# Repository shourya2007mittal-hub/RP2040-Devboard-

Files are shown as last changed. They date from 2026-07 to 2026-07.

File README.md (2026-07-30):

# RP2040-Devboard-



SO I made a custom Rp2040 Dev-board for myself . I tried to make a dev board in which I have the access to almost all the gpio/analog pins available on the Rp2040 . It also holds an USB-C Type interference for communication and 3.3V Voltage regulator and Crystal oscillator , Flash Memory , boot pin and LEDS and battery connector and more.

## Features

- Based on RP-2040 Chip
- Has MCP1700x-330xxTT as Voltage Regualtor 
- Has W25Q16JVUXIQTR as Flash Memory
- Uses 2 set of 18 connector pins
- Has on-Board LEDS and battery connector 

## Cost Summary (BOM)

| Item | Quantity | Price (USD) | Source |
|---|---|---|---|
| PCB + PCBA + Shipping  | 1 | $83.94 | JLCPCB |

**Total Estimated Cost:** **$83.94**

### Schematic


### PCB Design



### 3D Design



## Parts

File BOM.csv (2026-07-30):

Item | Quantity | Price | Source
PCB + PCBA + Shipping | 1 | 83.94 | JLCPCB

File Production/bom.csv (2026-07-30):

Designator | Footprint | Quantity | Value | LCSC Part #
C1 | 0402 | 1 | 1uF
C13, C14 | 0603 | 2 | 10uF
C15, C16 | 0402 | 2 | 33pF
C17, C2, C3, C4, C5, C6, C7, C8, C9 | 0402 | 9 | 0.1uF
D1, D4, D5 | 0201 | 3 | LED
J1 | USB_C_Receptacle_G-Switch_GT-USB-7010ASV | 1 | USB_C_Receptacle_USB2.0_16P
J2, J3 | PinHeader_1x20_P2.54mm_Vertical | 2 | Conn_01x20
J4 | PinHeader_1x03_P2.54mm_Vertical | 1 | Conn_01x03
J6 | Hirose_DF13-02P-1.25DSA_1x02_P1.25mm_Vertical | 1 | Conn_01x02_Pin
R1, R2 | 0603 | 2 | 33 R
R10, R12, R13 | 0603 | 3 | 1K
R3, R4 | 0603 | 2 | 50K
R5, R6 | 0402 | 2 | 1K
R7 | 0402 | 1 | 10K
R8, R9 | 0402 | 2 | 27
SW1 | SW_Push_SPST_NO_Alps_SKRK | 1 | SW_Push
U1 | QFN-56-1EP_7x7mm_P0.4mm_EP3.2x3.2mm | 1 | RP2040
U2 | SOT-23 | 1 | MCP1700x-330xxTT
U4 | Winbond_USON-8-1EP_3x2mm_P0.5mm_EP0.2x1.6mm | 1 | W25Q16JVUXIQ TR
Y1 | Crystal_SMD_3225-4Pin_3.2x2.5mm | 1 | 12 MHz

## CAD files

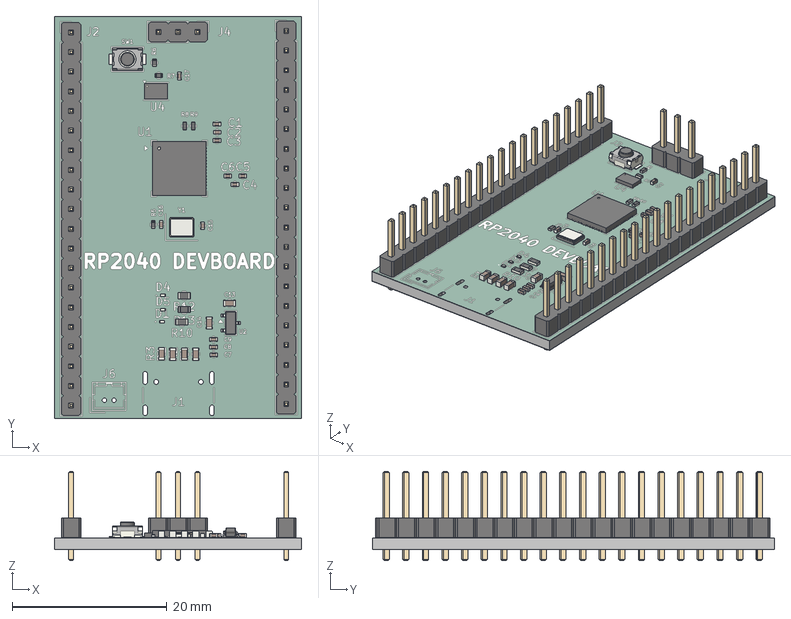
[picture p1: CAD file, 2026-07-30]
CAD/RP2040 Devboard.step
32.0 x 52.0 x 11.5 mm
C_0402_1005Metric x 12
R_0402_1005Metric x 5
Winbond_USON-8-1EP_3x2mm_P0.5mm_EP0.2x1.6mm
LED_0201_0603Metric x 3
C_0603_1608Metric x 6
R_0603_1608Metric x 3
QFN-56-1EP_7x7mm_P0.4mm_EP3.2x3.2mm
PinHeader_1x20_P2.54mm_Vertical x 2
SW_Push_SPST_NO_Alps_SKRK
Crystal_SMD_3225-4Pin_3.2x2.5mm
SOT-23
PinHeader_1x03_P2.54mm_Vertical
RP2040 Devboard_silkscreen
RP2040 Devboard_soldermask x 2
RP2040 Devboard_PCB

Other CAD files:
CAD/RP2040 Devboard.f3d

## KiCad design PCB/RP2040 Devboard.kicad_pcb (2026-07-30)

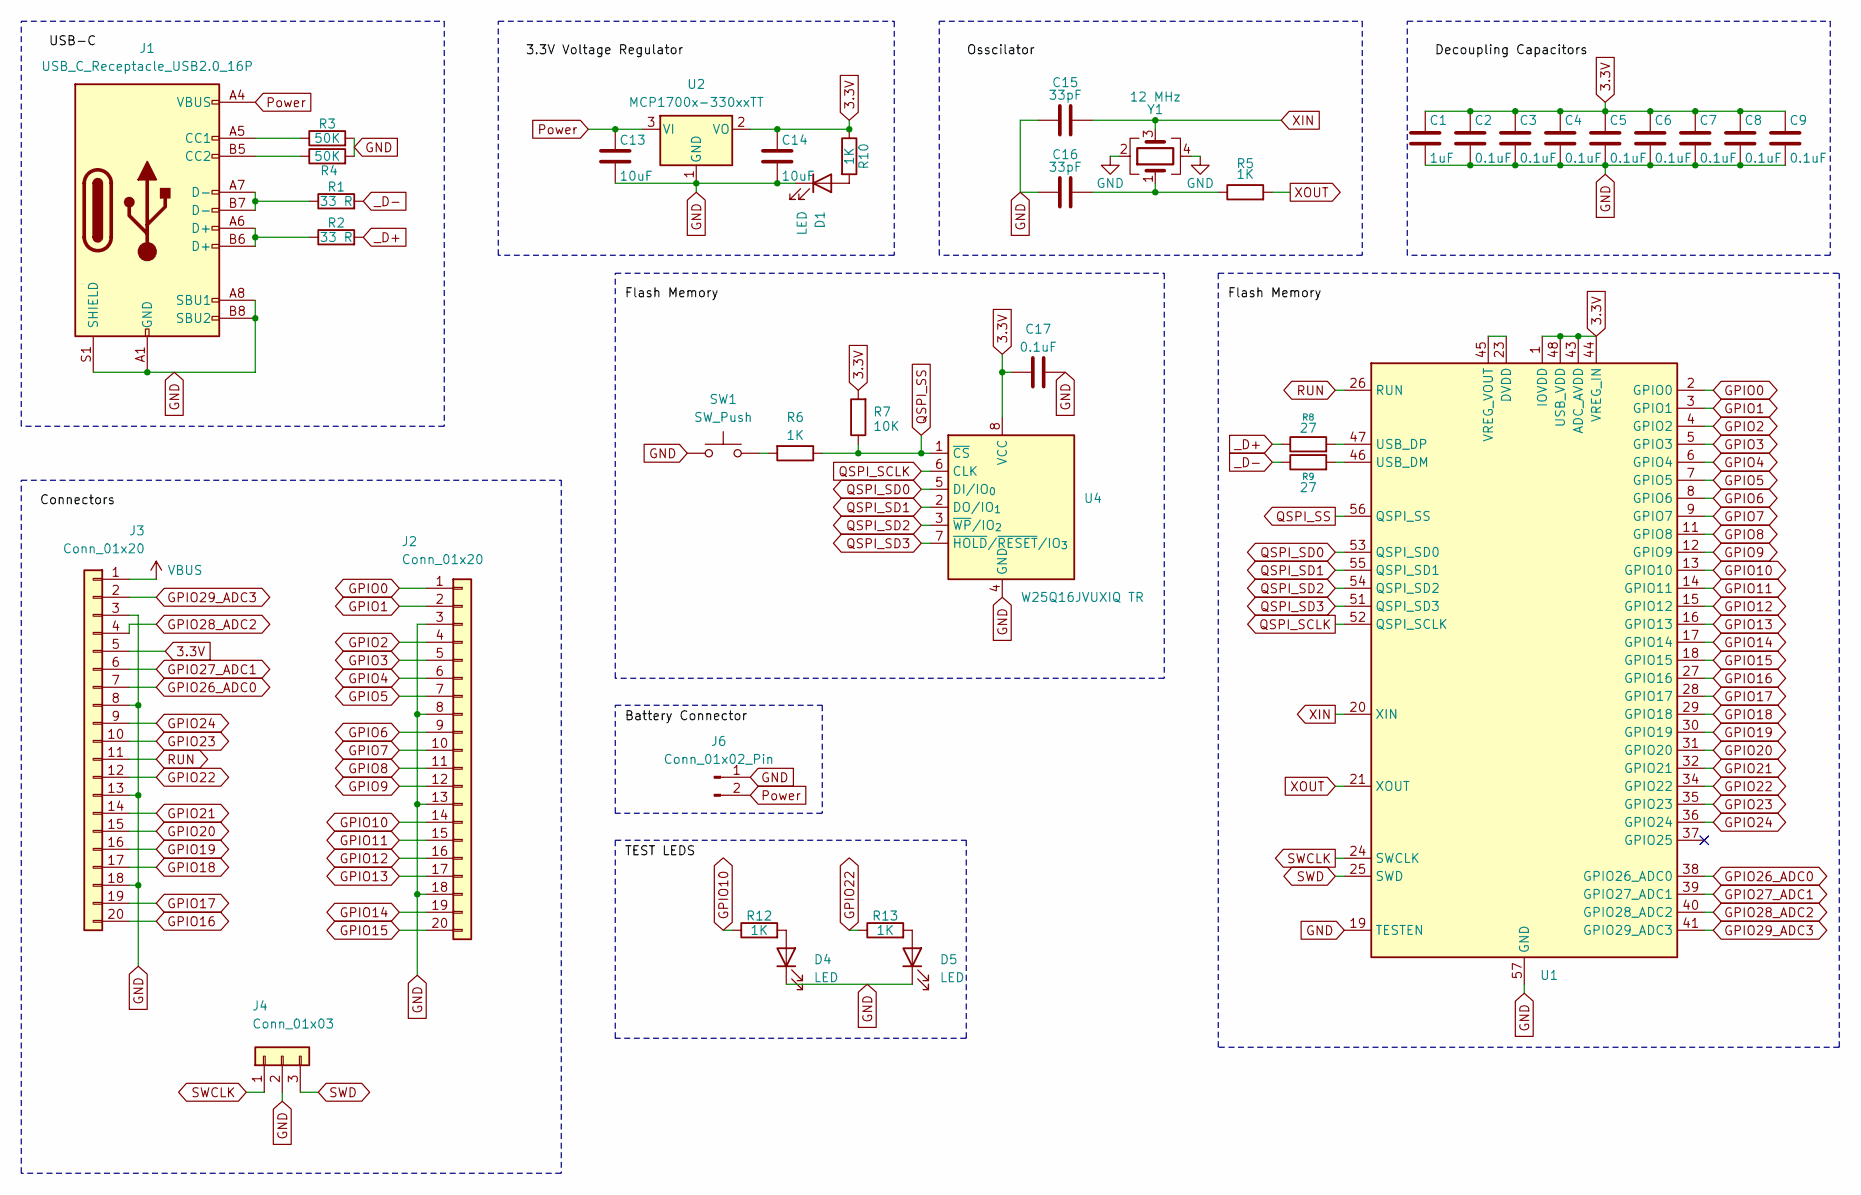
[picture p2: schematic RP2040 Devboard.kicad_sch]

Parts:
C1: 1uF; C_0402_1005Metric
C2, C3, C4, C5, C6, C7, C8, C9, C17: 0.1uF; C_0402_1005Metric
C13, C14: 10uF; C_0603_1608Metric
C15, C16: 33pF; C_0402_1005Metric
D1, D4, D5: LED; LED_0201_0603Metric
J1: USB_C_Receptacle_USB2.0_16P; USB_C_Receptacle_G-Switch_GT-USB-7010ASV
J2, J3: Conn_01x20; PinHeader_1x20_P2.54mm_Vertical
J4: Conn_01x03; PinHeader_1x03_P2.54mm_Vertical
J6: Conn_01x02_Pin; Hirose_DF13-02P-1.25DSA_1x02_P1.25mm_Vertical
R1, R2: 33 R; C_0603_1608Metric
R3, R4: 50K; C_0603_1608Metric
R5, R6: 1K; R_0402_1005Metric
R7: 10K; R_0402_1005Metric
R8, R9: 27; R_0402_1005Metric
R10, R12, R13: 1K; R_0603_1608Metric
SW1: SW_Push; SW_Push_SPST_NO_Alps_SKRK
U1: RP2040; QFN-56-1EP_7x7mm_P0.4mm_EP3.2x3.2mm
U2: MCP1700x-330xxTT; SOT-23
U4: W25Q16JVUXIQ TR; Winbond_USON-8-1EP_3x2mm_P0.5mm_EP0.2x1.6mm
Y1: 12 MHz; Crystal_SMD_3225-4Pin_3.2x2.5mm

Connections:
3.3V: C1.1, C2.1, C3.1, C4.1, C5.1, C6.1, C7.1, C8.1, C9.1, C14.1, C17.1, J3.5, R7.2, R10.1, U1.1 (IOVDD), U1.10 (IOVDD), U1.22 (IOVDD), U1.33 (IOVDD), U1.42 (IOVDD), U1.43 (ADC_AVDD), U1.44 (VREG_IN), U1.48 (USB_VDD), U1.49 (IOVDD), U2.2 (VO), U4.8 (VCC)
GND: C1.2, C2.2, C3.2, C4.2, C5.2, C6.2, C7.2, C8.2, C9.2, C13.2, C14.2, C15.1, C16.1, C17.2, D1.1 (K), D4.1 (K), D5.1 (K), J1.A1 (GND), J1.A8 (SBU1), J1.A12 (GND), J1.B1 (GND), J1.B8 (SBU2), J1.B12 (GND), J1.S1 (SHIELD), J2.3, J2.8, J2.13, J2.18, J3.3, J3.8, J3.13, J3.18, J4.2, J6.1, R3.2, R4.2, SW1.1, U1.19 (TESTEN), U1.57 (GND), U2.1 (GND), U4.4 (GND), Y1.2, Y1.4
GPIO0: J2.1, U1.2 (GPIO0)
GPIO1: J2.2, U1.3 (GPIO1)
GPIO2: J2.4, U1.4 (GPIO2)
GPIO3: J2.5, U1.5 (GPIO3)
GPIO4: J2.6, U1.6 (GPIO4)
GPIO5: J2.7, U1.7 (GPIO5)
GPIO6: J2.9, U1.8 (GPIO6)
GPIO7: J2.10, U1.9 (GPIO7)
GPIO8: J2.11, U1.11 (GPIO8)
GPIO9: J2.12, U1.12 (GPIO9)
GPIO10: J2.14, R12.1, U1.13 (GPIO10)
GPIO11: J2.15, U1.14 (GPIO11)
GPIO12: J2.16, U1.15 (GPIO12)
GPIO13: J2.17, U1.16 (GPIO13)
GPIO14: J2.19, U1.17 (GPIO14)
GPIO15: J2.20, U1.18 (GPIO15)
GPIO16: J3.20, U1.27 (GPIO16)
GPIO17: J3.19, U1.28 (GPIO17)
GPIO18: J3.17, U1.29 (GPIO18)
GPIO19: J3.16, U1.30 (GPIO19)
GPIO20: J3.15, U1.31 (GPIO20)
GPIO21: J3.14, U1.32 (GPIO21)
GPIO22: J3.12, R13.1, U1.34 (GPIO22)
GPIO23: J3.10, U1.35 (GPIO23)
GPIO24: J3.9, U1.36 (GPIO24)
GPIO26_ADC0: J3.7, U1.38 (GPIO26_ADC0)
GPIO27_ADC1: J3.6, U1.39 (GPIO27_ADC1)
GPIO28_ADC2: J3.4, U1.40 (GPIO28_ADC2)
GPIO29_ADC3: J3.2, U1.41 (GPIO29_ADC3)
unnamed: C16.2, R5.1, Y1.1
unnamed: D1.2 (A), R10.2
unnamed: D4.2 (A), R12.2
unnamed: D5.2 (A), R13.2
unnamed: J1.A5 (CC1), R3.1
unnamed: J1.B5 (CC2), R4.1
unnamed: J1.A6 (D+), J1.B6 (D+), R2.1
unnamed: J1.A7 (D-), J1.B7 (D-), R1.1
unnamed: R6.2, SW1.2
unnamed: R9.2, U1.46 (USB_DM)
unnamed: R8.2, U1.47 (USB_DP)
unnamed: U1.23 (DVDD), U1.45 (VREG_VOUT), U1.50 (DVDD)
Power: C13.1, J1.A4 (VBUS), J1.A9 (VBUS), J1.B4 (VBUS), J1.B9 (VBUS), J6.2, U2.3 (VI)
QSPI_SCLK: U1.52 (QSPI_SCLK), U4.6 (CLK)
QSPI_SD0: U1.53 (QSPI_SD0), U4.5 (DI/IO_{0})
QSPI_SD1: U1.55 (QSPI_SD1), U4.2 (DO/IO_{1})
QSPI_SD2: U1.54 (QSPI_SD2), U4.3 (~WP/IO_{2})
QSPI_SD3: U1.51 (QSPI_SD3), U4.7 (~HOLD/~RESET/IO_{3})
QSPI_SS: R6.1, R7.1, U1.56 (QSPI_SS), U4.1 (~CS)
RUN: J3.11, U1.26 (RUN)
SWCLK: J4.1, U1.24 (SWCLK)
SWD: J4.3, U1.25 (SWD)
VBUS: J3.1
XIN: C15.2, U1.20 (XIN), Y1.3
XOUT: R5.2, U1.21 (XOUT)
_D+: R2.2, R8.1
_D-: R1.2, R9.1

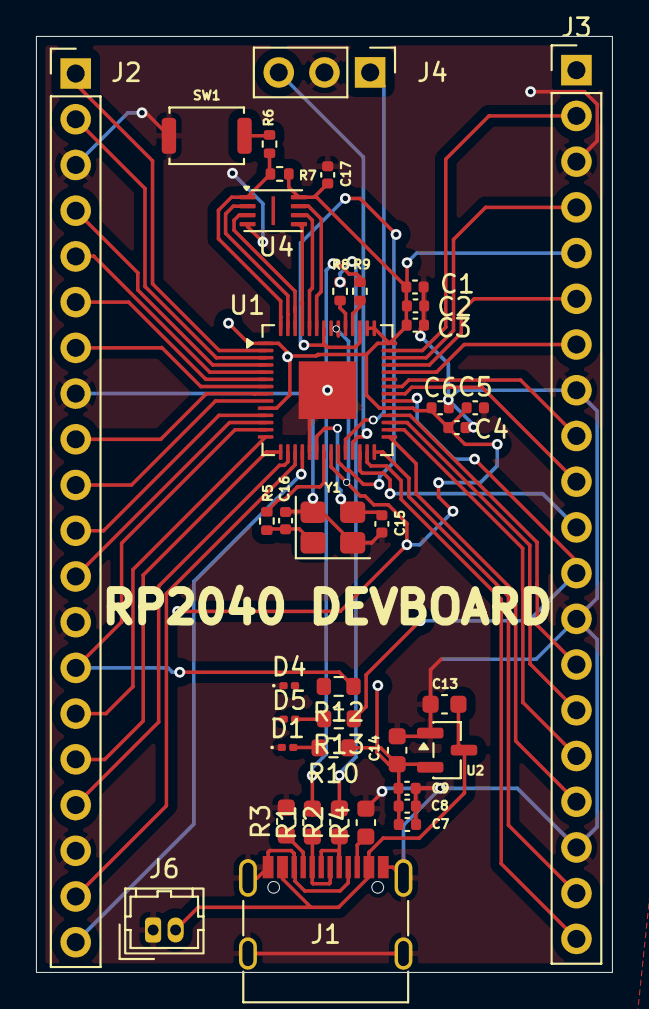
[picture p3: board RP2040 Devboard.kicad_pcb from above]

Board: 2 copper layers, 32.0 x 52.0 mm, 39 parts (0 on the bottom side), 57 nets.
